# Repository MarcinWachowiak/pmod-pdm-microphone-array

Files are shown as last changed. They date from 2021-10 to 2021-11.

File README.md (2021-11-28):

# Pmod PDM microphone array
<div align="justify">
Pmod module with multiple PDM microphones to enable array audio signal processing. Microphones are arranged in a linear array with a spacing of λ/2 at 3 kHz. The Pmod interface enables easy and straightforward evaluation with popular FPGA development boards. Used IM69D130 microphones have matched phase response (±2°) and small sensitivity tolerance (±1dB).
</div>
<br>

  - **Manufactured prototypes**
  
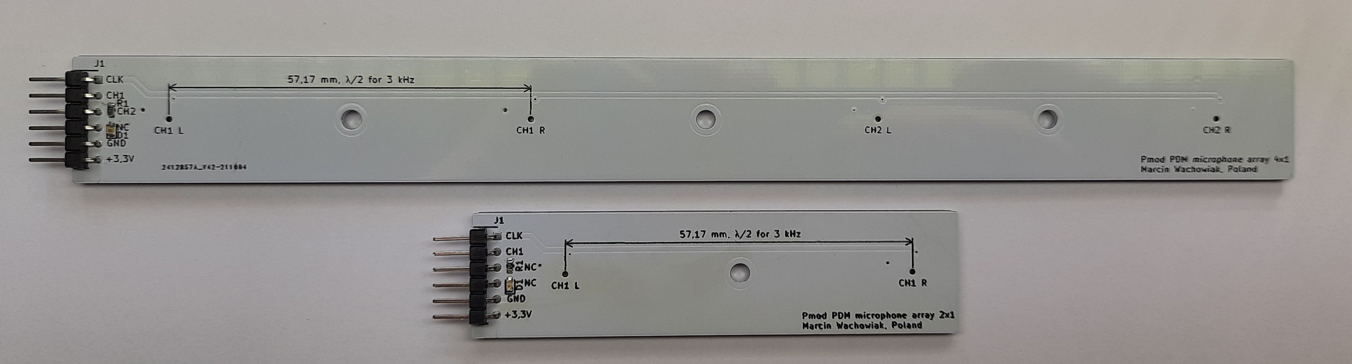
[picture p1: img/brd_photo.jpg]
    

 **Available configurations**:

  - **2x1**

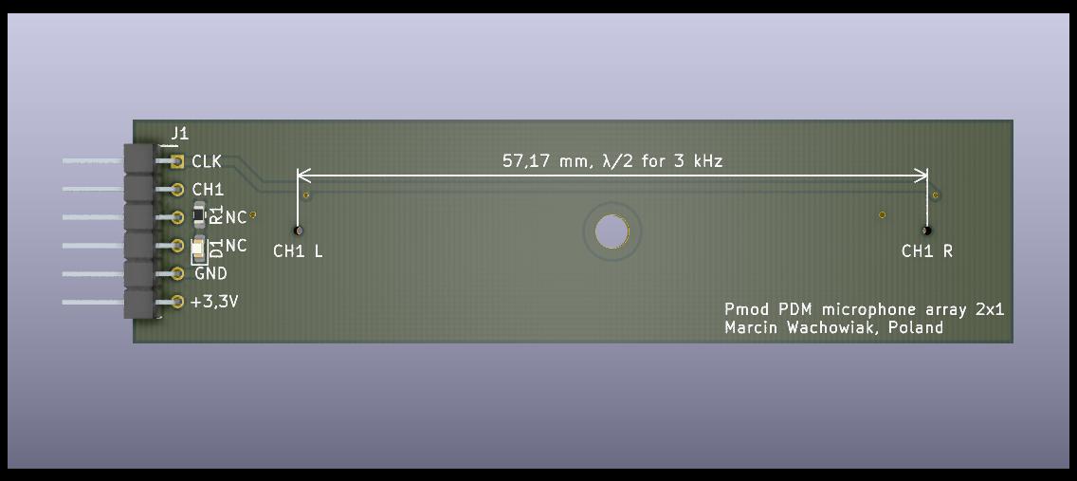
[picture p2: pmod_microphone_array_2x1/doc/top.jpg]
    
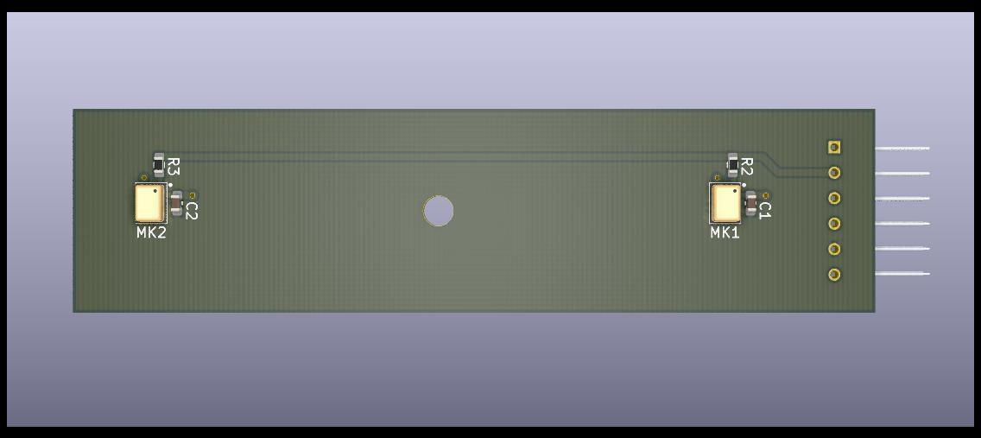
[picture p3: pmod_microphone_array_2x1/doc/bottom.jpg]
2x1_bottom
    

  - **4x1**
    
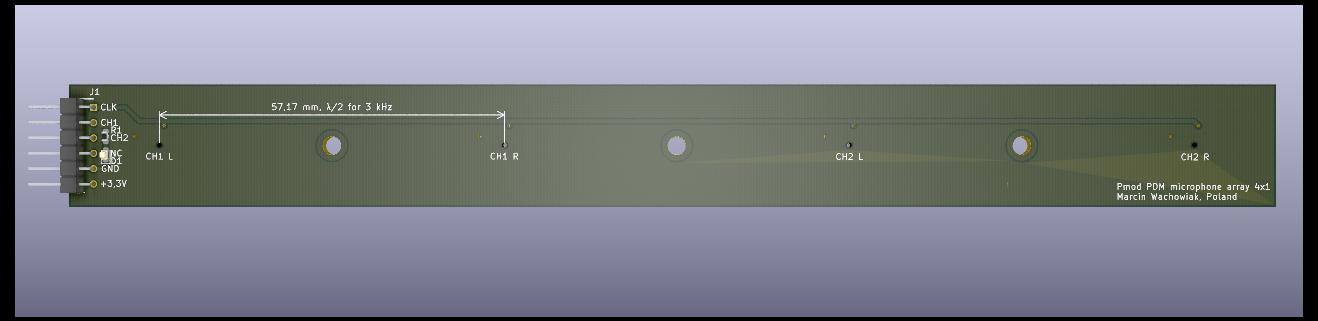
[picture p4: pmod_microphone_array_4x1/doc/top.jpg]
4x1_top
    
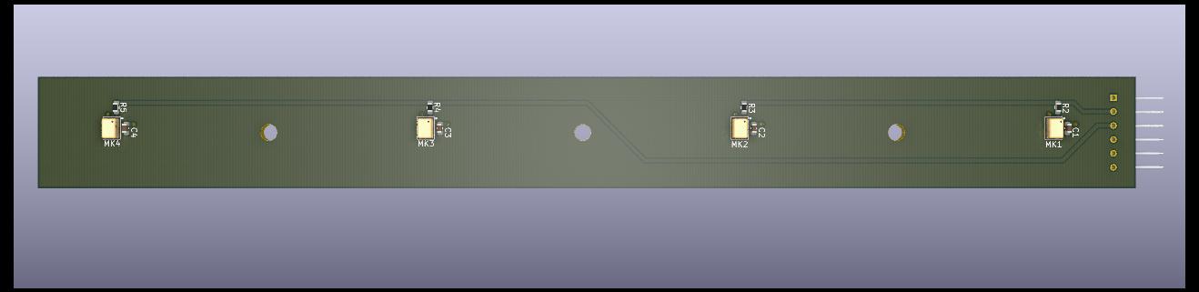
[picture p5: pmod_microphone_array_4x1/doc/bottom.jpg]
4x1_bottom
    

  - **2x2**

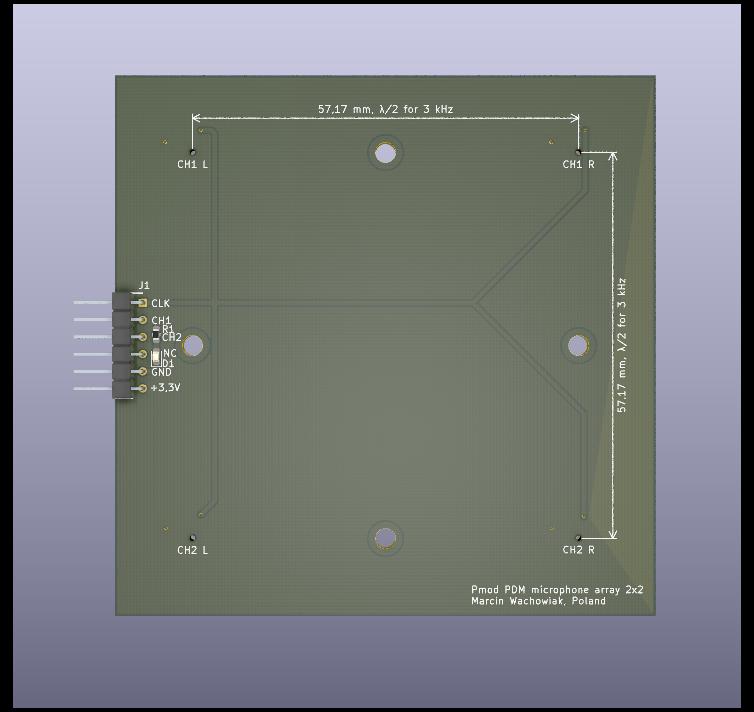
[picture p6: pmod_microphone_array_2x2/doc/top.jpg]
    
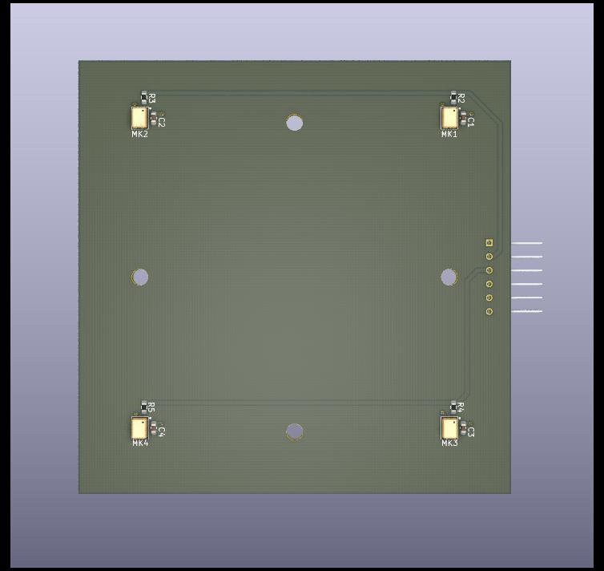
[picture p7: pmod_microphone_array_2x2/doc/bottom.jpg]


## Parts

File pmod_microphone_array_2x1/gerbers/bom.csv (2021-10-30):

Source: | /home/marcin/Desktop/Projects/Pmod-PDM-microphone-array/pmod_microphone_array_2x1/pmod_microphone_array_2x1.sch
Date: | nie, 26 wrz 2021, 10:09:13
Tool: | Eeschema 5.1.10-88a1d61d58~88~ubuntu18.04.1
Generator: | /usr/share/kicad/plugins/bom_csv_grouped_by_value_with_fp.py
Component Count: | 9
Ref | Qnty | Value | Cmp name | Footprint | Description | Vendor
C1, C2, | 2 | 100n/16V | C | Capacitor_SMD:C_0603_1608Metric | Unpolarized capacitor
D1, | 1 | GREEN | LED | LED_SMD:LED_0603_1608Metric | Light emitting diode
J1, | 1 | 61300611021 | 61300611021 | pmod_microphone_array:61300611021 | Wurth Elektronik WR-PHD 6130, 2.54mm Pitch, 6 Way, 1 Row, Right Angle Pin Header, Through Hole
MK1, MK2, | 2 | IM69D130V01XTSA1 | IM69D130V01XTSA1 | pmod_microphone_array:IM69D130V01XTSA1
R1, R2, R3, | 3 | 100 | R | Resistor_SMD:R_0603_1608Metric | Resistor

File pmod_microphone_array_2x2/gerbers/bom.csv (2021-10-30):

Source: | /home/marcin/Desktop/Projects/Pmod-PDM-microphone-array/pmod_microphone_array_2x2/pmod_microphone_array_2x2.sch
Date: | nie, 26 wrz 2021, 13:45:38
Tool: | Eeschema 5.1.10-88a1d61d58~88~ubuntu18.04.1
Generator: | /usr/share/kicad/plugins/bom_csv_grouped_by_value_with_fp.py
Component Count: | 15
Ref | Qnty | Value | Cmp name | Footprint | Description | Vendor
C1, C2, C3, C4, | 4 | 100n/16V | C | Capacitor_SMD:C_0603_1608Metric | Unpolarized capacitor
D1, | 1 | GREEN | LED | LED_SMD:LED_0603_1608Metric | Light emitting diode
J1, | 1 | 61300611021 | 61300611021 | pmod_microphone_array:61300611021 | Wurth Elektronik WR-PHD 6130, 2.54mm Pitch, 6 Way, 1 Row, Right Angle Pin Header, Through Hole
MK1, MK2, MK3, MK4, | 4 | IM69D130V01XTSA1 | IM69D130V01XTSA1 | pmod_microphone_array:IM69D130V01XTSA1
R1, R2, R3, R4, R5, | 5 | 100 | R | Resistor_SMD:R_0603_1608Metric | Resistor

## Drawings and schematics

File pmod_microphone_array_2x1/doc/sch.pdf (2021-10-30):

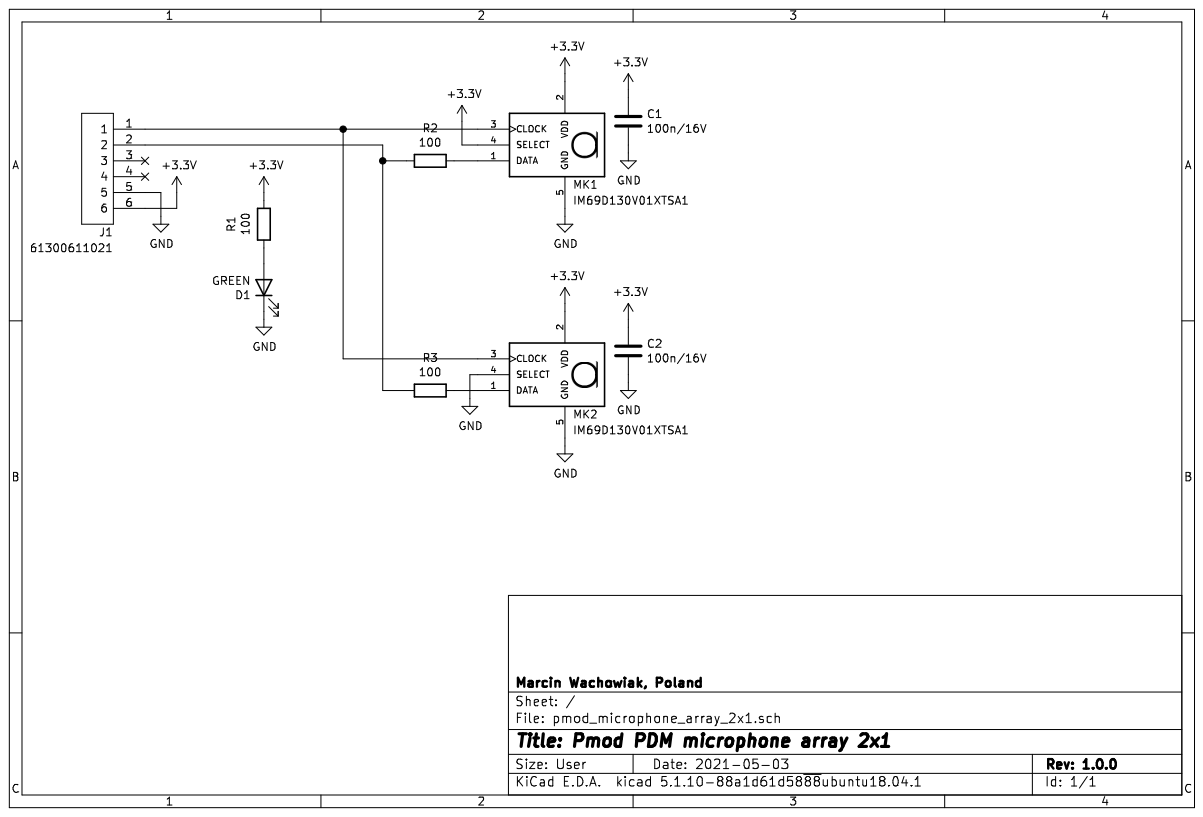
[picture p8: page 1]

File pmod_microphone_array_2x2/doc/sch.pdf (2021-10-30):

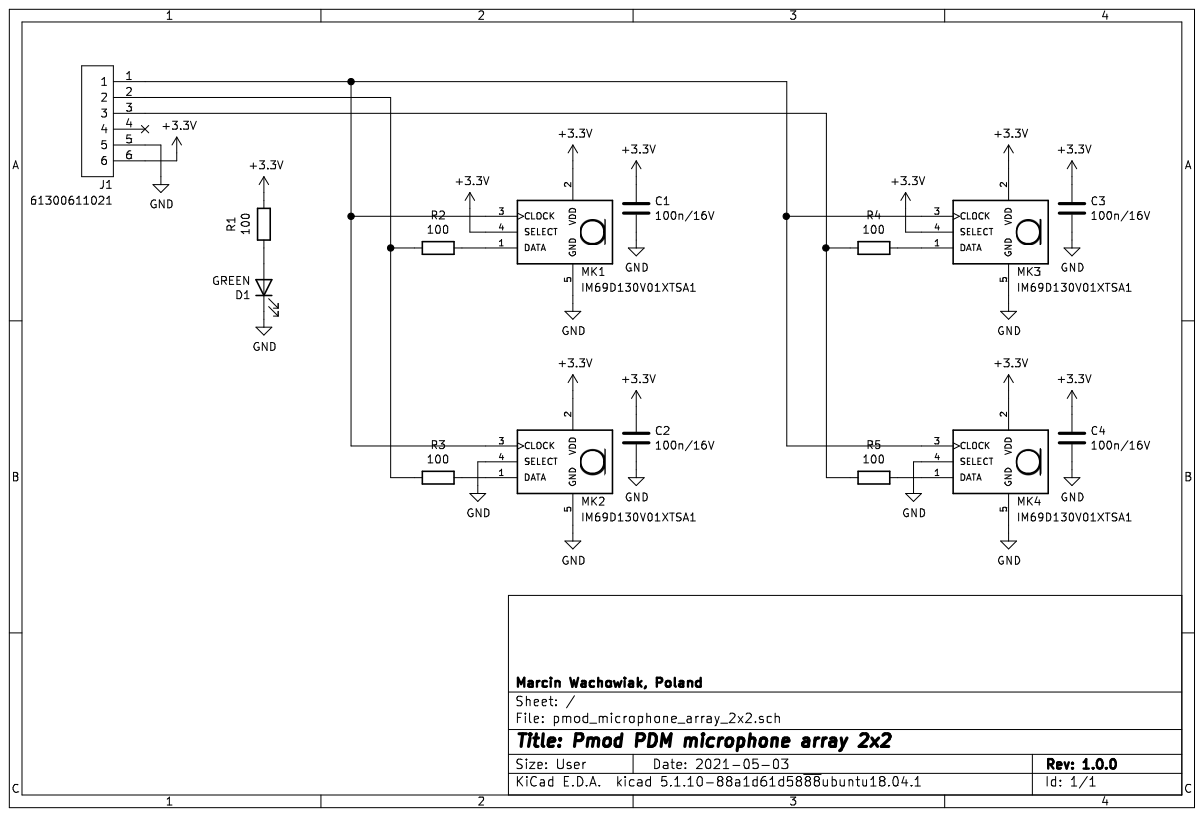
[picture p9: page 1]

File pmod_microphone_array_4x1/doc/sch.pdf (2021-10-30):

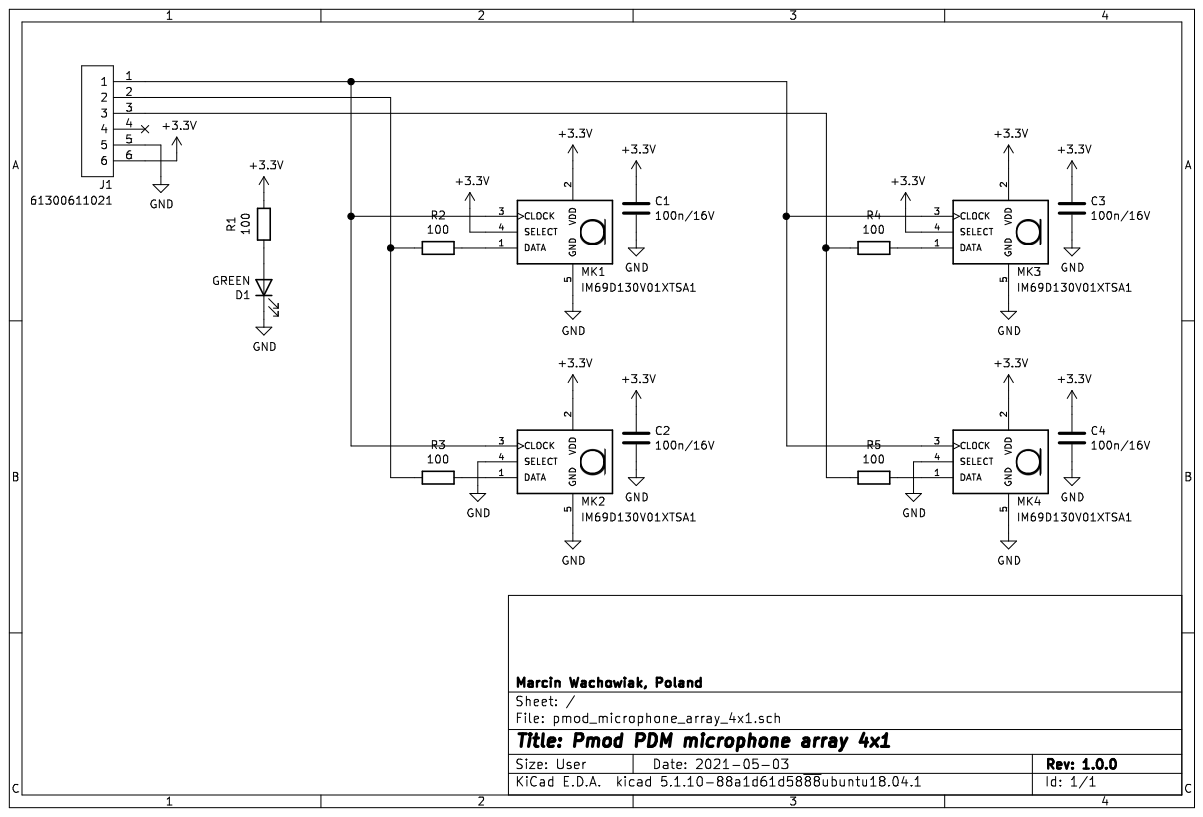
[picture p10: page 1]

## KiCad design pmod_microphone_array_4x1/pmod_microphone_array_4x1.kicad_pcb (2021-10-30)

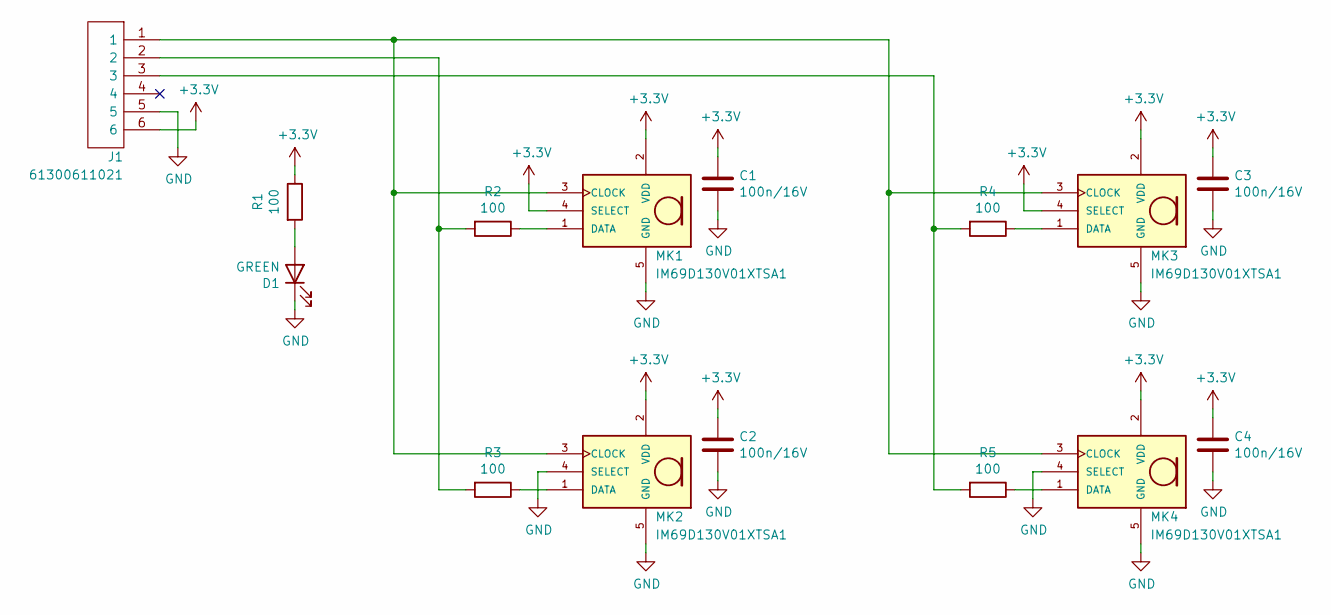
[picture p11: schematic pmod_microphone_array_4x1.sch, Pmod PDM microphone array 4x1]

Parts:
C1, C2, C3, C4: 100n/16V; C_0603_1608Metric
D1: GREEN; LED_0603_1608Metric
J1: 61300611021; Manufacturer_Part_Number 61300611021; Mouser Part Number 710-61300611021
MK1, MK2, MK3, MK4: IM69D130V01XTSA1; Manufacturer_Part_Number IM69D130V01XTSA1
R1, R2, R3, R4, R5: 100; R_0603_1608Metric

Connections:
+3V3: C1.1, C2.1, C3.1, C4.1, J1.6, MK1.2 (VDD), MK1.4 (SELECT), MK2.2 (VDD), MK3.2 (VDD), MK3.4 (SELECT), MK4.2 (VDD), R1.1
GND: C1.2, C2.2, C3.2, C4.2, D1.1 (K), J1.5, MK1.5 (GND), MK2.4 (SELECT), MK2.5 (GND), MK3.5 (GND), MK4.4 (SELECT), MK4.5 (GND)
unnamed: D1.2 (A), R1.2
unnamed: J1.1, MK1.3 (CLOCK), MK2.3 (CLOCK), MK3.3 (CLOCK), MK4.3 (CLOCK)
unnamed: J1.2, R2.2, R3.2
unnamed: J1.3, R4.2, R5.2
unnamed: MK1.1 (DATA), R2.1
unnamed: MK2.1 (DATA), R3.1
unnamed: MK3.1 (DATA), R4.1
unnamed: MK4.1 (DATA), R5.1

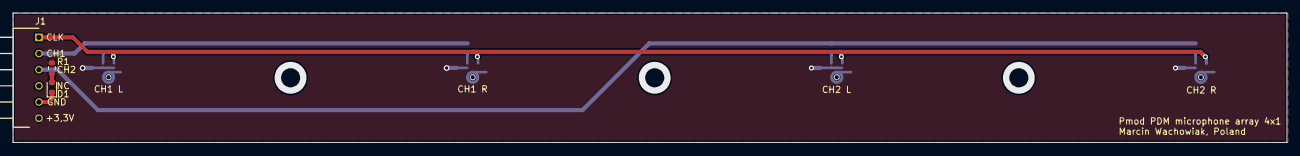
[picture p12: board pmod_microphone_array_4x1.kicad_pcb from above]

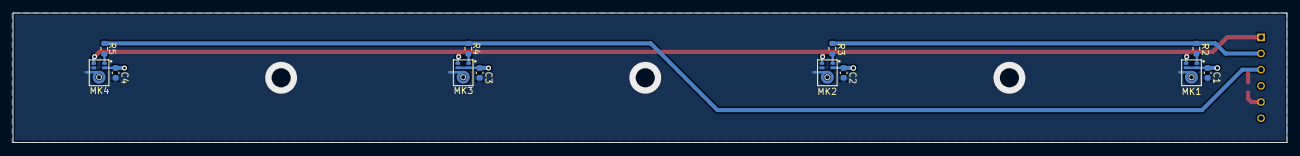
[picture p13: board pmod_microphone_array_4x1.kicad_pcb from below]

Board: 2 copper layers, 200.0 x 20.3 mm, 15 parts (12 on the bottom side), 10 nets.
